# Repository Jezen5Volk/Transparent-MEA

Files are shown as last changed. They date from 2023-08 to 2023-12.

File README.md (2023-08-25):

# Transparent-MEA
The first (major) prototype for this project involved making a wafer design that contained 400 electrodes. The associated Altium design files and KLayout gds files are stored in the directory named *400 Electrode GDS files*.

The second prototype for this project involved expanding the design to cover the entire surface of a 4-inch wafer, as well as reducing the number of electrodes to maximize the size of bond pads. This permitted me to wire bond to the wafer easier. The associated Altium and KLayout files are located in the directory named *324 Electrode GDS files*.

The third prototype for this project shrank the design to 64 electrodes to permit the wafer and surrounding electronics to fit inside a 3.5 cm diameter petri dish. Additionally, wafer prototyping has reached a point where it is becoming necessary to make a custom stage of built in stimulation electronics for the wafer, to allow tissue on the device to be simultaneously stimulated and viewed optically. The directory named *64 Electrode Stimulation* contains the design files for both the wafer and the stimulation electronics.

The directory named *Altium Library* contains the schematic libraries containing the custom footprints and symbols made for components on this project.

Photo gallery (screenshots/images of work I did that I thought was interesting from this project): 

400 electrode wafer
324 electrode wafer
64 electrode wafer
Top MEA PCB
64 electrode wafer 3 mm by 3mm
Inverted Microscope Stim PCB
324 electrode sensing area close up
gold bond pads wafer
Gold wire bonds

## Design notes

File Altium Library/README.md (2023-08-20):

This directory contains Altium library files containing all the relevant schematics, footprints, and associations of the two for every wafer made and for each custom component on the stimulation board.

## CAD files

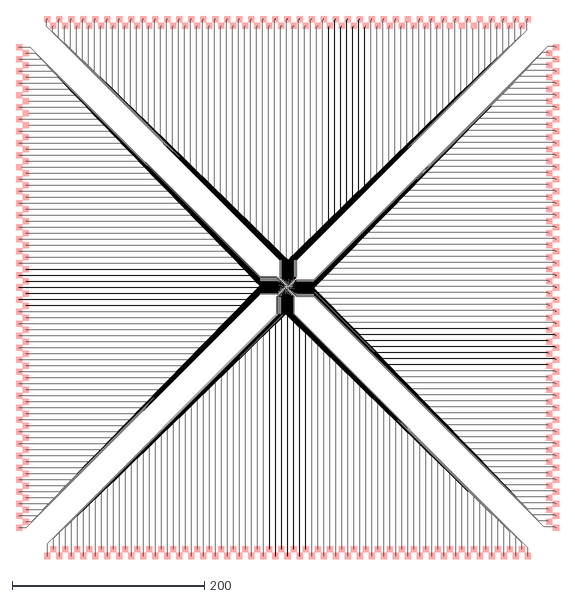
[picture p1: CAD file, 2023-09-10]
324 Electrode Wafer/324 Electrode Wafer PCB.DXF
565.0 x 565.0

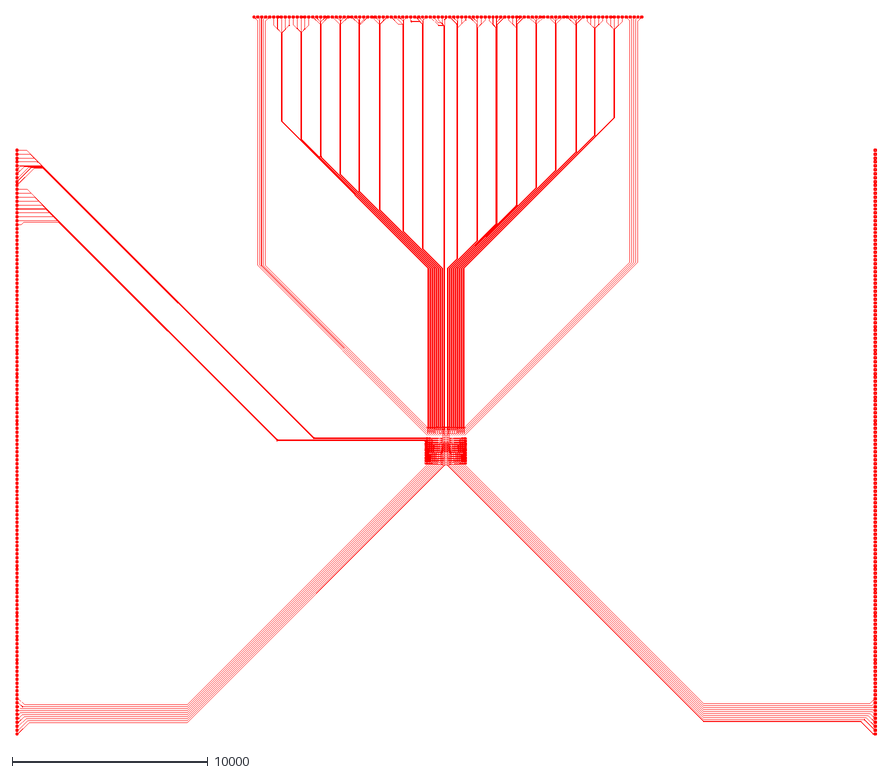
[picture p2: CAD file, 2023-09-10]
400 Electrode Wafer/Wafer_PCB_ no_squares_scaled.DXF
43900.0 x 36700.0

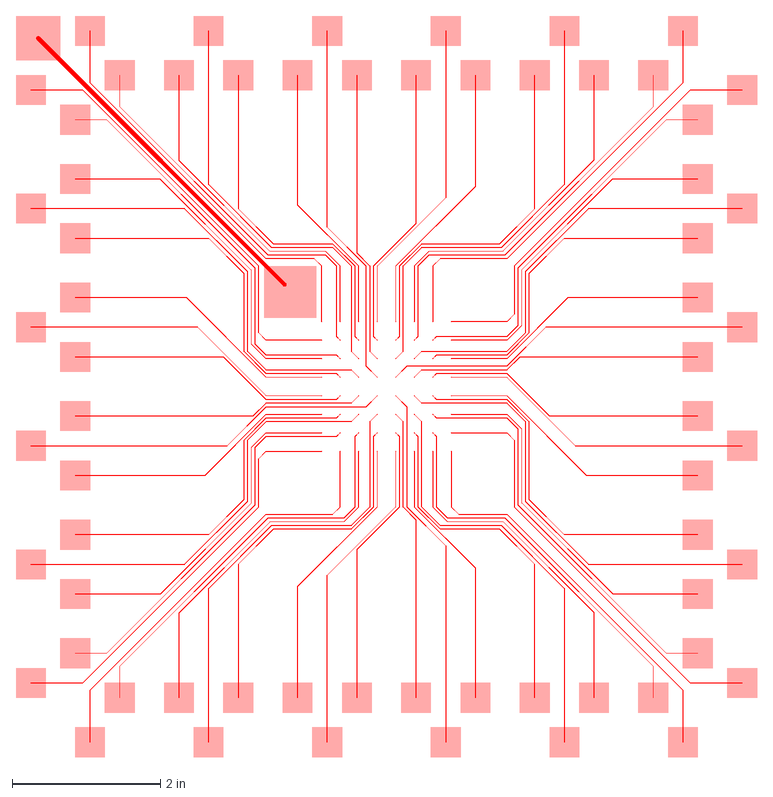
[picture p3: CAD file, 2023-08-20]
64 Electrode Stimulation/64 Electrode Wafer/1 mm x 1 mm Design/64 Electrode Wafer PCB.DXF
10.0 x 10.0 in

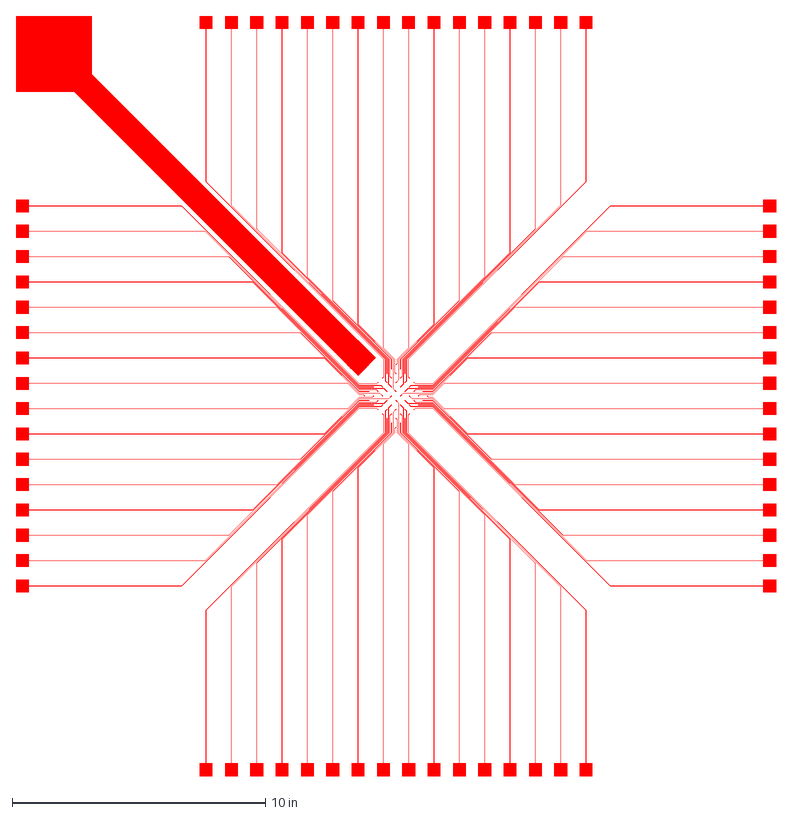
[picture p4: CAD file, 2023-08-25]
64 Electrode Stimulation/64 Electrode Wafer/3 mm x 3 mm Design/64 Electrode Wafer PCB.DXF
30.0 x 30.0 in

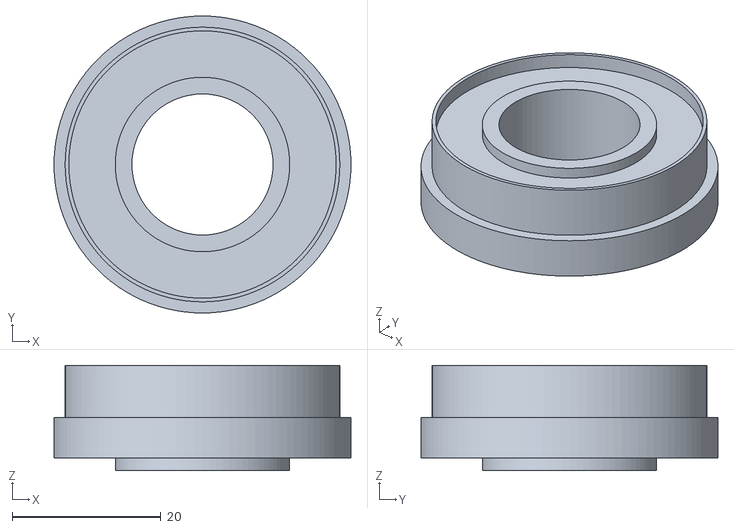
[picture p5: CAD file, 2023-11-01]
64 Electrode Stimulation/Stimulation PCB/Inverted Microscope/64 Electrode Stim Board Ring v3.stl
40.0 x 40.0 x 14.2

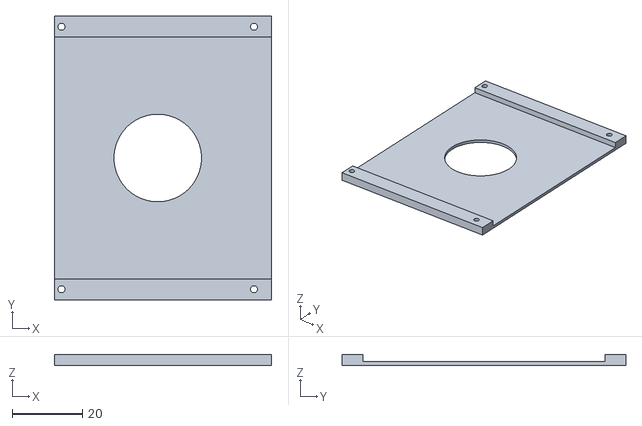
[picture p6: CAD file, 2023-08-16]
324 Electrode Wafer/324 electrode pcb v1 lid v1.stl
62.0 x 81.0 x 3.00

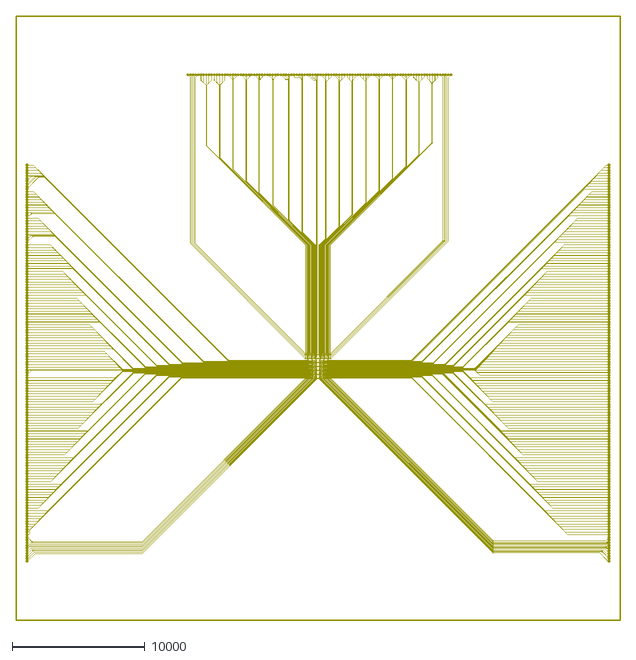
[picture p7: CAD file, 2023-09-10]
400 Electrode Wafer/WaferPCB.DXF
45430.0 x 45430.0

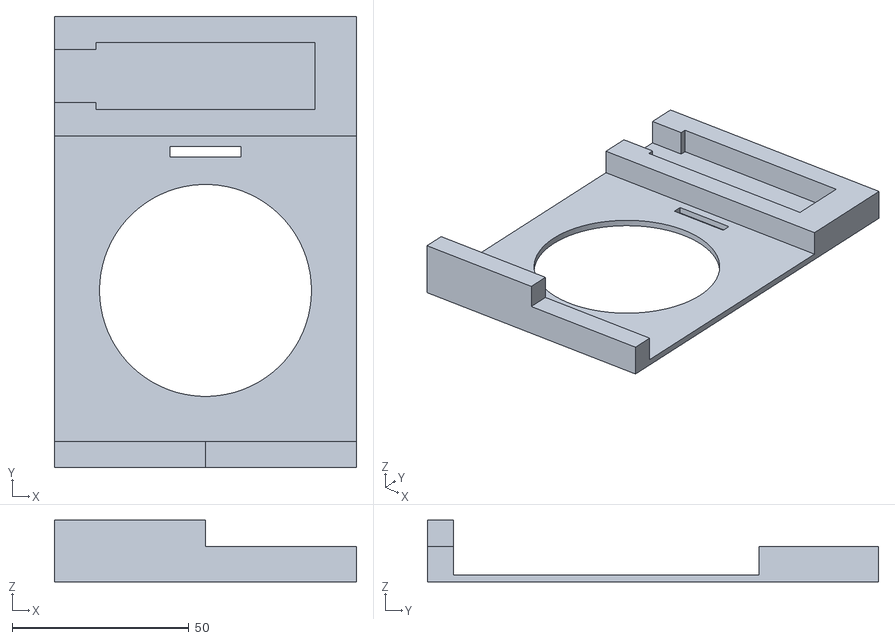
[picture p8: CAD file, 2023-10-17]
64 Electrode Stimulation/Stimulation PCB/Inverted Microscope/64 Electrode Stim Board Inverted Microscope Fixture v5.stl
85.5 x 127.8 x 17.5

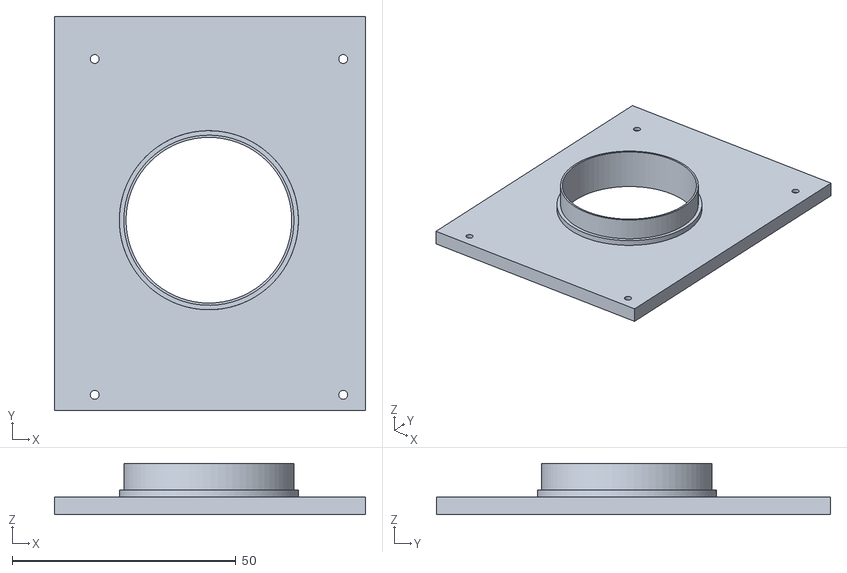
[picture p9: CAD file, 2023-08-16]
324 Electrode Wafer/324 electrode wafer containment v2.stl
69.5 x 88.0 x 11.5

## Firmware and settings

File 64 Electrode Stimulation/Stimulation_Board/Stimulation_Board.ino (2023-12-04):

/*
The MIT License (MIT)

Author: Samantha Herman (They/Them), Bouwmeester Group — UCSB

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
THE SOFTWARE IS PROVIDED "AS IS", WITHOUT WARRANTY OF ANY KIND, EXPRESS OR IMPLIED,
INCLUDING BUT NOT LIMITED TO THE WARRANTIES OF MERCHANTABILITY, FITNESS FOR A
PARTICULAR PURPOSE AND NONINFRINGEMENT. IN NO EVENT SHALL THE AUTHORS OR COPYRIGHT
HOLDERS BE LIABLE FOR ANY CLAIM, DAMAGES OR OTHER LIABILITY, WHETHER IN AN ACTION OF
CONTRACT, TORT OR OTHERWISE, ARISING FROM, OUT OF OR IN CONNECTION WITH THE SOFTWARE
OR THE USE OR OTHER DEALINGS IN THE SOFTWARE.
*/

#include "DAC_Commands.h"
#include "Programs.h"
#include <Arduino.h>
#include <SPI.h>

PROGRAM stim; //define PROGRAM object for running functions

/*
    Things to note: 
        -If you wish to enable all electrodes, replace stim.burst(...) with stim.burst_all(...);

        -If you wish to stimulate a selection of electrodes simultaneously, set e_dly to 0

        -If you want a longer delay before the program starts running, increase the delay in void setup()
*/

/*-------------------------------
USER PROGRAMMABLE HYPERPARAMETERS
-------------------------------*/

unsigned long int freq = 50;                       //frequency in Hz of stimulation signals [Hz]
unsigned long int e_dly = 5;                       //delay between activating sequential electrodes in milliseconds [mS]
unsigned long int puls_dur_pos = 1000;             //duration of positive voltage signal in microseconds [uS] 
unsigned long int puls_dur_neg = 1000;             //duration of negative voltage signal in microseconds [uS]
unsigned long int brst_dur = 55;                   //duration of voltage waveform in seconds [S]
unsigned long int quiet_dur = 5;                  //duration of silent period in seconds [S]
int rounds = 3;                                    //number of repetitions of burst + quiet periods [unitless]
float amp_pos = 5;                                 //amplitude of positive voltage in range from (2.5, 5] Volts [V]
float amp_neg = 0;                                 //amplitude of negative voltage in range from [0, 2.5) Volts [V]
std::vector<int> e = {12, 53, 5, 0};               //electrodes in order of stimulation from [0, 63]

/*------------------------------
NOTHING ELSE NEED BE MODIFIED :)
------------------------------*/



void setup(){
    //Let the user know programming has started
    pinMode(LED_BUILTIN, OUTPUT);
    digitalWrite(LED_BUILTIN, HIGH);
    delay(1000);

    //Run the program
    stim.start_up();
    stim.burst(freq, e_dly, puls_dur_pos, puls_dur_neg, brst_dur, quiet_dur, rounds, amp_pos, amp_neg, e);
    
    //End SPI transaction so that the LED can be turned back on
    SPI.end(); 
};


void loop(){
    //Blink the LED to indicate that the program has finished
    digitalWrite(LED_BUILTIN,HIGH); 
    delay(500);
    digitalWrite(LED_BUILTIN,LOW);
    delay(500);
};

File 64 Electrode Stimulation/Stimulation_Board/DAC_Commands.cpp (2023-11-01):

//Local Headers
#include "DAC_Commands.h"

//STL Headers
#include <cmath>
#include <bitset>
#include <string>
#include <vector> 

//3rd Party Headers
#include <Arduino.h>
#include <SPI.h>
#include <elapsedMillis.h>


/*-----------------
Low Level Functions
-----------------*/

void DAC::xfer_data(std::string data, int size){

    //Convert binary string into array of bytes, MSB First
    uint8_t byte_stream[size];
    for (int i = 0; i < size; i++){
      std::string byte_string = data.substr(i*8, 8);
      uint8_t byte = std::bitset<8>(byte_string).to_ulong();
      byte_stream[i] = byte;
    }

    //Transfer byte stream over SPI, one byte at a time
    digitalWrite(SYNCpin, LOW);
    for (unsigned int i = 0; i < sizeof(byte_stream); i++){
        SPI.transfer(byte_stream[i]);
    }
    digitalWrite(SYNCpin, HIGH);

};

//Resets to zero scale
void DAC::reset(){

    digitalWrite(RESETpin, LOW);
    elapsedMicros RESET_timer;
    if (RESET_timer >= 1){
        digitalWrite(RESETpin, HIGH);
    };

}; 


/*--------------------
Medium Level Functions
--------------------*/

//Daisy Chain Enable
void DAC::DCEN(){

    //Make data strings to transfer
    std::string DCEN_cmd = std::bitset<4>(1000).to_string(); //1000 command: Set up the daisy-chain enable (DCEN) register
    std::string DCEN = std::bitset<20>(1).to_string(); //toggling LSB enables/disables daisy chain mode
    std::string DCEN_word = DCEN_cmd + DCEN;
    std::string no_op = std::bitset<24>(0).flip().to_string(); //1111 command: no operation, in daisy chain mode

    //Enable Daisy Chaining on each DAC sequentially starting at DAC 1
    for(int i = 1; i <= N_DACS; i++){
        std::string data_word;
        for(int j = 0; j < i; j++){
            if(j == 0){
                data_word = DCEN_word;
            }
            else{
                data_word = data_word + no_op;
            }
        }
        xfer_data(data_word, i*3);
    }

};   
    
//Write a voltage to a DAC Register
void DAC::write_DAC_reg(float voltage, int reg){

    //Convert to 12 bit voltage + 4 don't care bits
    int v_res = std::floor(voltage/DAC_RES);
    std::string voltage_bits = std::bitset<12>(v_res).to_string();
    std::string dc_bits = std::bitset<4>(0).to_string();  

    //Convert register number to 4 bit address and combine with write command
    int DAC_num = reg/16;
    std::string address = std::bitset<4>(reg - DAC_num*16).to_string();
    std::string command_wrt = std::bitset<4>(0001).to_string(); //0001 command: writes to addressed input register

    //Combine voltage, don't care, address, and command bits
    std::string voltage_word = command_wrt + address + voltage_bits + dc_bits;

    //Combine voltage word with no operation command for data word for all DACs
    std::string data_word;
    std::string no_op = std::bitset<24>(0).flip().to_string(); //1111 command: no operation, in daisy chain mode
    for (int i = N_DACS; i > 0; i--){
        if (i == DAC_num + 1){
            data_word = data_word + voltage_word;
        }
        else{
            data_word = data_word + no_op;
        }
    }
    
    //Send data word through SPI
    xfer_data(data_word, N_DACS*3);

}; 


/*------------------
High Level Functions
------------------*/

//Resets all DAC outputs to REF voltage (2.5 V) 
void DAC::ref_reset(){
    
    for(int i = 0; i < 16*N_DACS; i ++){
        write_DAC_reg(2.5, i);
    }

    //ensure LDAC is held low long enough 
    digitalWrite(LDACpin, LOW);
    elapsedMicros LDAC_timer; 
    if (LDAC_timer >= 1){
        digitalWrite(LDACpin, HIGH);
    }

}; 

//Writes voltage to selected registers simultaneously
void DAC::sync_write(float voltage, std::vector<int> regs){

    for(unsigned int i = 0; i < sizeof(regs) - 1; i++){
        write_DAC_reg(voltage, regs[i]);
    }

    //ensure LDAC is held low long enough 
    digitalWrite(LDACpin, LOW);
    elapsedMicros LDAC_timer; 
    if (LDAC_timer >= 1){
        digitalWrite(LDACpin, HIGH);
    }


}; 

//Writes voltage to selected registers sequentially with delay in mSec
void DAC::seq_write(float voltage, std::vector<int> regs, long unsigned int seq_delay){

    digitalWrite(LDACpin, LOW); //when LDAC is low, the input register is transparent
    elapsedMillis timer;
    for(unsigned int i = 0; i < sizeof(regs) - 1; i++){
        write_DAC_reg(voltage,regs[i]);
        while(timer <= seq_delay){}; //delay without occupying hardware
        timer = 0;
    }
    
    //ensure LDAC is held low long enough 
    elapsedMicros LDAC_timer; 
    if (LDAC_timer >= 1ULL){
        digitalWrite(LDACpin, HIGH);
    }

}; 

void DAC::p_pulse(unsigned long int e_dly, unsigned long int puls_dur_pos, unsigned long int puls_dur_neg, unsigned long int brst_dur, float amp_pos, float amp_neg, std::vector<int> regs){
    
    //Stimulate each electrode simultaneously
    if (e_dly == 0){
        elapsedMicros clock;
        if(clock <= puls_dur_pos){
            sync_write(amp_pos, regs);
        };
        if(clock > puls_dur_pos && clock < puls_dur_pos + puls_dur_neg){
        sync_write(amp_neg, regs);
        };
        if(clock >= puls_dur_pos + puls_dur_neg){
        sync_write(2.5, regs); //at pulse end, set back to ref voltage
        };
    }

    //Stimulate each electrode with delay between each electrode
    else{
        digitalWrite(LDACpin, LOW); //when LDAC is low, the input register is transparent
        elapsedMillis clock_ms;
        elapsedMicros clock_us;
        for(unsigned int i = 0; i < sizeof(regs) - 1; i++){
            while(clock_ms < e_dly){
                if (clock_us <= puls_dur_pos){
                    write_DAC_reg(amp_pos, regs[i]); 
                };
                if (clock_us > puls_dur_pos && clock_us < puls_dur_pos + puls_dur_neg){
                    write_DAC_reg(amp_neg, regs[i]);
                };
                if (clock_us >= puls_dur_pos + puls_dur_neg){
                    write_DAC_reg(2.5, regs[i]); //at pulse end, set back to ref voltage
                };
            }
            clock_ms = 0;
            clock_us = 0;
        }
    
        //ensure LDAC is held low long enough 
        elapsedMicros LDAC_timer; 
        if (LDAC_timer >= 1){
            digitalWrite(LDACpin, HIGH);
        }
    }

};

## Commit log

2023-08-16 Added PCB Design files
    [Organoid Sensing Silicon Wafer Design.PrjPcb, Wafer Schematic.SchDoc, WaferPCB.PcbDoc]
2023-08-25 Updated Libraries(64 inv microscope MEA + wafer)
    [Silicon Die Holders.PcbLib, Silicon Die Holders.SchLib]
2023-08-25 Uploaded project files from Altium
    [64 Electrode Inverted Microscope Schematic.SchDoc, 64 Electrode Inverted Microscope.PcbDoc, 64 Electrode Wafer (Inverted Microscope).PrjPcb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]
2023-08-25 Upload project files from Altium
    [64 Channel Stimulation Board (Petri Dish).PrjPcb, Bottom MEA (Inverted Microscope).PcbDoc, Stimulation Stage.SchDoc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]
2023-08-25 Upload project files from KLayout
    [64 Electrode Wafer PCB.DXF]
2023-09-09 fixed arduino spelling
2023-09-10 Renamed "...Wafer GDS" to "...Wafer"
    [324 Electrode Wafer PCB.DXF, 324 Electrode Wafer PCB.PcbDoc, 324 Electrode Wafer Schematic.SchDoc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]
2023-09-10 Reorganized 64 Electrode Stimulation directory
2023-09-10 wrote write_DAC_reg function
    [TestCPP.obj]
2023-09-11 xfer_data and write_DAC_reg fully functional
    [TestCPP.obj]
2023-09-11 Completed High Level Functions
    [TestCPP.obj]
2023-09-11 swapped arrays for std::vector
    Did this to enable reincluding size to make xfer_data versatile enough to be able to handle sending data to any number of DACS from one DAC or N_DACS
    [DAC_Commands.cpp, DAC_Commands.h]
2023-09-11 DCEN function written
    [TestCPP.obj]
2023-09-12 5V-->3.3V on SPI Bus Connector
    [Silicon Die Holders.SchLib]
2023-09-12 Revisision 2.1 of the Stimulation PCB
    Fixed board cutout in the middle, tied the reference voltage of all DACs to the reference electrode of the MEA, tied the gain pin to the 1.8 V_Logic pin, removed the 3.3 voltage regulator, shortened path lengths where possible, and increased the width of the power trace to 1 mm from 0.25 mm
    [64 Channel Stim (Inverted Microscope).PcbDoc, 64 Channel Stimulation Board (Inverted Microscope).PrjPcb, Stimulation Stage (Inverted).SchDoc]
2023-10-01 added p_pulse() + bug fix seq_write()
    [TestCPP.obj]
2023-10-02 all code finished
    [TestCPP.obj]
2023-10-05 Altered to compile on Teensy 4.1
2023-10-17 Inverted Microscope Fixture
    [64 Electrode Stim Board Inverted Microscope Fixture v5.stl]
2023-10-20 Added MEA_Ring.stl
    [64 Electrode Stim Board Ring v3.stl]
2023-11-01 Fixed bug in xfer_data function
    [DAC_Commands.cpp, Programs.cpp, Stimulation_Board.ino]
